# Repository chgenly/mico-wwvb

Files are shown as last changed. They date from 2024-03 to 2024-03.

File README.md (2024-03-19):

# &mu;WWVB: a tiny wwvb station

&mu;WWVB is a low power 60 khz [WWVB] transmitter used
to automatically set the time on radio synchronized clocks and wristwatches where the regular [WWVB] signal isn’t available. The system acquires
the correct time via GPS.

If you are interested in building a WWVB transmitter, I recommend you look at [pico wwvb](https://github.com/chgenly/pico-wwwvb).  It's much cheaper to build, and a lot less work.

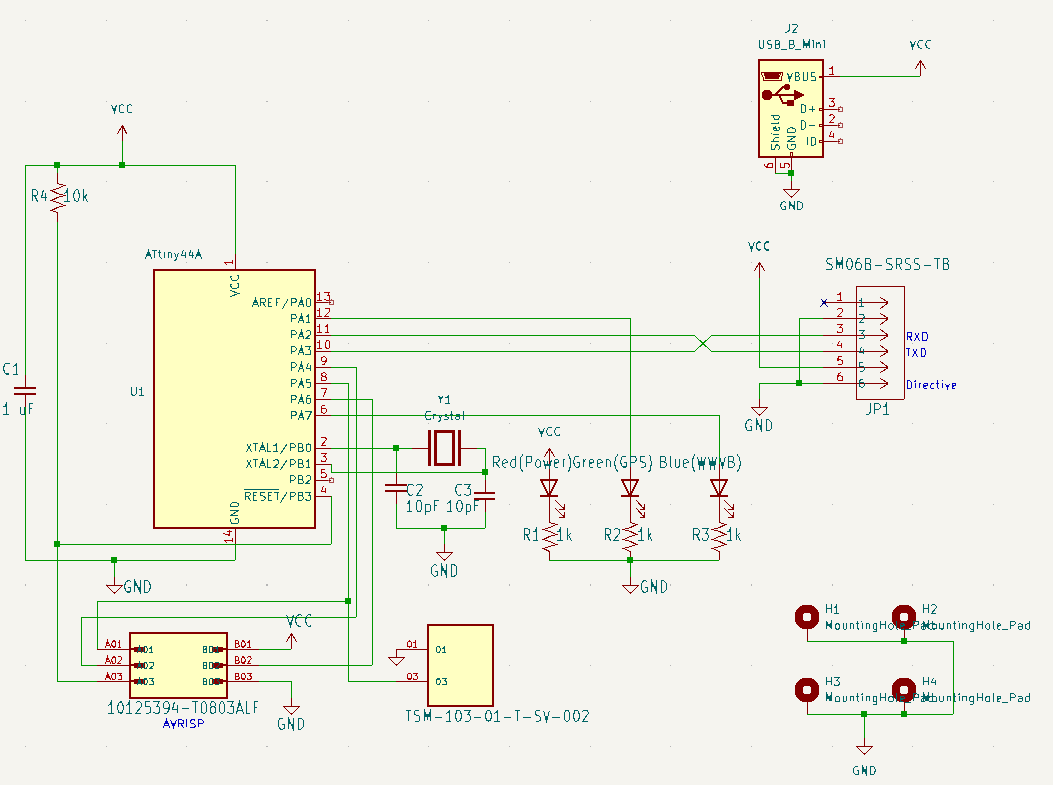
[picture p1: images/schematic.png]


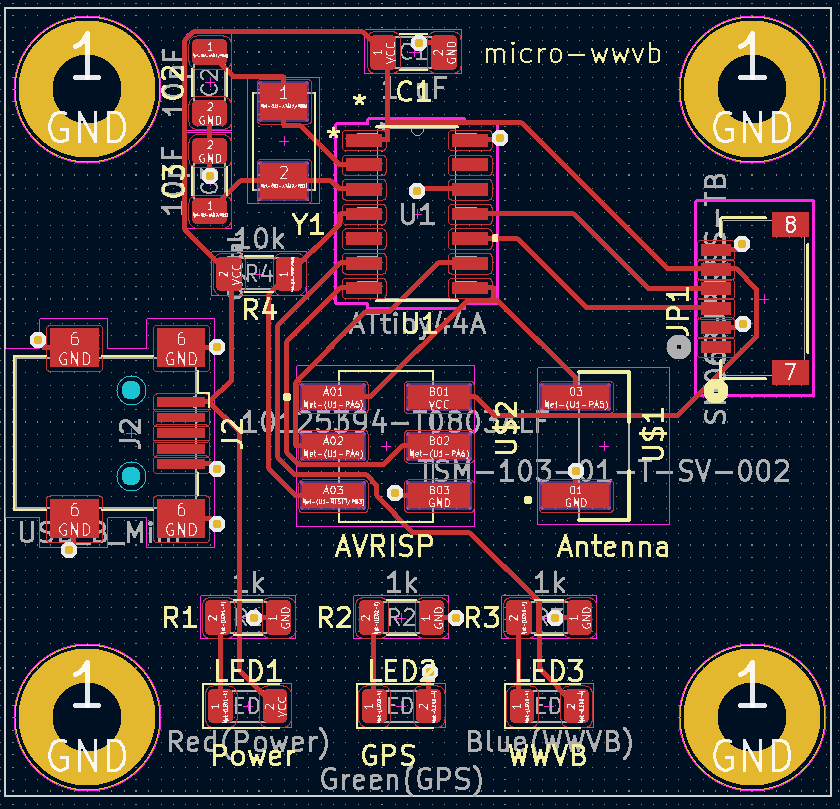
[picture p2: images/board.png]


## Anish Athalye's project

I started with this 2016 github project.

-  His github project https://github.com/anishathalye/micro-wwvb.git 
-  His [blog post][micro-wwvb-post].

Thanks to Anish for making it available. 

## My situation

I live in Forest Grove, Oregon.  The opposite coast where Anish had his problem. I'm not able to reliably receive [WWVB], and especially not inside my house.  

I started searching for information on WWVB signals and ran 
across Anish's project.  It was perfect for what I wanted to do.

Anish seemed to have access to a lot of equipment for building the physical part of the stand.    I don't have access so I'm just going to be using a simple plastic box as a case.

I haven't made my own PC board since 1974.  A lot of taping was involved and then an etching bath.  I was pleased to discover open source schematic and printed circuit board editors.  I was
also pleased to discover online services which would accept design files, either as [gerber files](https://en.wikipedia.org/wiki/Gerber_format) or kicad pcb files, and mail you a finished PCB.

## KiCad

For my open source schematic/PCB editor I chose [KiCad].  I had never used it before.  So there was a bit of a learning curve.

### autorouting
Install the Freerouting plugin.
1. Open KiCad Project Manager
1. Click on Plugin and Content Manager
1. Find Freerouting
1. Click on install
1. Click on Apply Pending Changes.
1. You will have to have Java installed for it to work.

## PCB fabrication service

I used [Osh Park](https://oshpark.com) as my fabrication service.  They accept KiCad pcb files directly.  No need to export to gerber files.  The are the cheapest service I could fine.  Interestingly, they just happen to be local to me.

[WWVB]: https://www.nist.gov/pml/time-and-frequency-division/radio-stations/wwvb
[micro-wwvb-post]: https://www.anishathalye.com/2016/12/26/micro-wwvb/

[KiCad]: https://www.kicad.org/

## ATTiny44a-SSUR

AVR family of processors.  8 bit risc architecture.

14 pin Dual inline package
Surfuce mount device

Just notes an decoding the suffix.

- 4KiB flash
- SS - 14S1 package
- U - Matte tin
- R - Tape and real
- 14S1 - 14-lead, 3.90 mm Narrow Body, Plastic Small Outline Package (SOIC)

## WWVB signal

WWVB transmit on 60 khz for atomic watches and clocks. One bit of data is sent once every second.
60 seconds are required to send all the bits for the time.
- 0: Power reduced for .2 seconds.
- 1: Power reduced for .5 seconds.
- mark: Power reduced for .8 seconds.

## Software

The top level software

1. Initialize pins for LEDs,  GPS serial communication and for the antenna. 
1. Loop
   1. Acquire time from GPS module
   1. Send the 1 minute WWVB signal ten times.

The 60 khz signal is generated using the ATTiny's 16 bit counter, and associated wave form generator.
The pulse width modulation output, PA5 (pin 8), is used to generate the 60khz signal.
The software divides a second into two parts.  The first part is the reduced power signal.  Reduced power in our case means no signal is sent.  The second part is full power signal.  Here pulse width modulation is set to 50% duty cycle.

Actually, a 20 khz signal is generated.  We depend on the third harmonic.  Apparently Anish found this more effective.

Timing for the signal is accomplished using a library routine to delay a certain number of milliseconds. I believe the millisecond
delay is trasformed to a cycle count delay.

During the full power signal, the blue led is turned on. The led is connected to PA7 (pin 6).

| Source file | Description |
|---|---|
| microwwvb.c | Top level.  init, get time, transmit time.|
| gps.c | Send and receive GPS module commands. |
| hardware.h  | Constants for LEDs, serial port |
| serial.c | Send and receive ascii data. |
| led.c | Show status on LEDs |

## Programming

For a description of using an arduino to program the micro-wwvb board see:

https://docs.arduino.cc/built-in-examples/arduino-isp/ArduinoISP

Here are the steps to use the arduino to program the micro-wwvb board.

1. Wire the Arduino to the micro-wwvb.
1. Program the Arduino as ISP.
1. Test program to make blue and green leds flash.
1. Update src/makefile
1. Program micro-wwvb

### Wire Arduino to the micro-wwvb

micro-wwwvb pin header, as seen when the usb connector is on the left.
<pre>
| miso  | vcc  |
| sck   | mosi |
| reset | gnd  |
</pre>

You'll need six male to female cables.

- miso - arduino 12
- sck - adruino 13
- reset - arduino 10
- vcc - arduino 5v
- mosi - arduino 11
- gnd - arduino gnd

Make sure to disconnnect the ferrite loop antenna during programming.

### Program the Arduino as ISP

- Connect Arduino uno to your laptop
- Start adrduino ide
- Select board: arduino uno
- Select comm: comm3 (for me)
- File / Examples/ Arduino ISP /ArduinoISP
- Sketch / Upload

## Test program to make blue and green leds flash

- File / Preferences
  - Select Show verbose output during compile and upload.
- Use the following sketch
- Select board: attiny44
- Select comm: com3 (for me)
  - You can use the windows device manager to help you find
    the com.  Look under Ports.
- Tools / Programmer / arduino as ISP
- Sketch / Upload using programmer

```c
// Flash blue and green LEDS.  Blue is on when green is off.
void setup() {
  pinMode(PA1, OUTPUT);
  pinMode(PA7, OUTPUT);
}

void loop() {
  digitalWrite(PA1, HIGH); 
  digitalWrite(PA7, LOW); 
  delay(100);
  digitalWrite(PA1, LOW);
  digitalWrite(PA7, HIGH);
  delay(100);
```

### Update src/makefile

The reason you turned on verbose mode in the previous step
was so you could see paths to various tools.  Look in the output window and look for the path to avr-gcc, avrdude, and avrdude-conf.
Then set the variables at the top of src/Makefile.

| Variable | Comment|
|---|---|
| GBIN | Should point to the directory containing avr-gcc.exe |
| DCONF | Should point to avrdude.conf |
| DBIN | Should be the directory containing avrdude.exe 

### Program micro-wwvb

Goto the src directory and run make.  I used cygwin make.

- make program-fuses
- make program

## LEDs

The LEDS will indicated status

| Time | LED states |
|---|-----|
| Program startup / top of loop | Green and blue flash three times |
| Waiting for start bit from GPS modules | Green  |
| Searching for the '$' at the start of the response from the GPS module | Blue |
| Complete time response received from GPS module | Green on |
| Failure to receive expected response from GPS module | Green blinks twice, then blue blinks twice. |
| While transmitting WWVB signal | Blue on for powered portion of the signal |

After startup, if the green and blue lights are stuck on,
you are not receiving anything from the GPS module.

After startup, if only the blue light is stuck on, 
you are receiving something from the GPS module, but the Initial '$' isn't being received.

If everything is working, you should see the Green light go solid, and the blue light flash
slowly with wwvb time data.

## Mechanical

To mount the gps module, which has no screw holes, I used a strap cut from a Fiji water bottle.  The Fiji bottle was rectangular, so I could cut out 
a relatively flat piece of plastic.  I created a template
in Gimp (image editor) and used a sharp craft knife to cut the plastic.

Here's the strap:
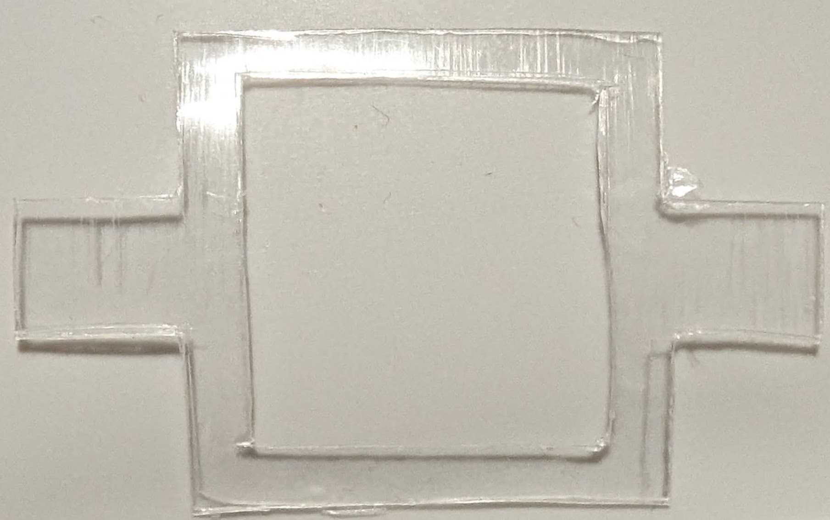
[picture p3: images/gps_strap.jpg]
GPS strap


You can see how the central hole is sized for the GPS module.
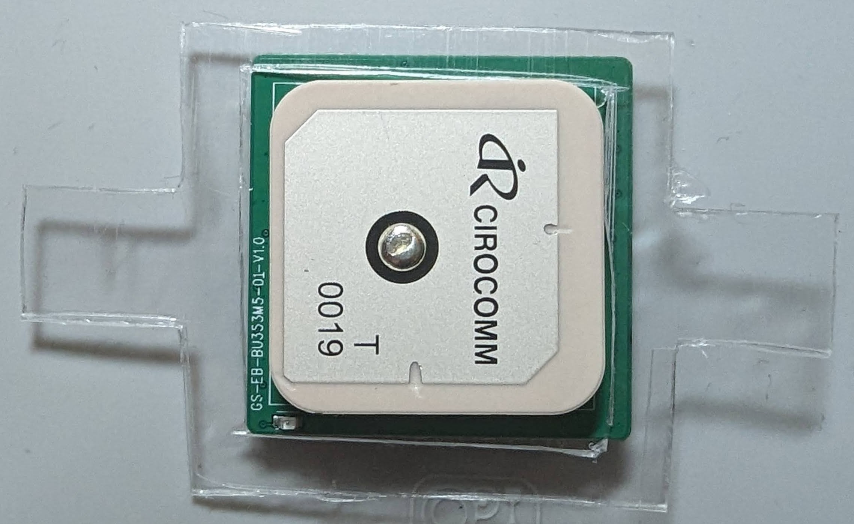
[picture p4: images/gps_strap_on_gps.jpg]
GPS strap on GPS module


I'll drill small holes in the tabs for screws.

I used a plastic food container as the case for the project.
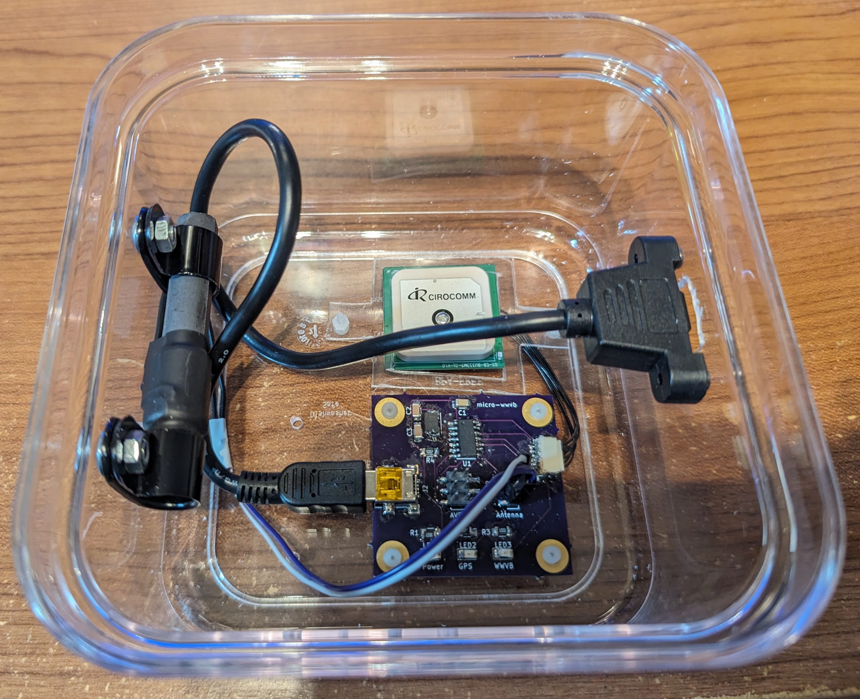
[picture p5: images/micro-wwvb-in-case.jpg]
micro-wwvb in a case

## Changes

### Board
My first attempt at the board was incorrect.  I got the order of the pins on the GPS connector backwards.  I didn't
realize the cable that came with the GPS module was a reversing cable.  I fixed this for my
purposes by using a non-reversing cable.  

I have updated the KiCAD files to fix the pin ordering problem.   The images of the schematic and
the board have been updated too.  However, I'v never had these boards manufactured, and so never 
tested the latest board design.  I don't expect you will have problems, but if you do, you can start looking there.

### GPS module

The original GPS modules was the EM-506.  Due to the pin ordering problem, I
burned out the GPS module.  When I went to reorder it, it wasn't available.
It had been changed to the EM-506N5.  They are largely compatible.  However
the module is no longer initialized using $PSRF commands, instead a
proprietary command, $PAIR, is used.  The software and the bill of materials
has been updated to reflect the new module.

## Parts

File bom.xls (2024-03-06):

Description | Quantity | Price | Total | Part Number | Url
Resistor 1K .5W 1206 | 3 | $0.40 | $1.20 | RNCP1206FTD1K00 | https://www.digikey.com/en/products/detail/stackpole-electronics-inc/RNCP1206FTD1K00/2240337
Resistor 10K .5W 1206 | 1 | $0.14 | $0.14 | RMEF1206FT10K0 | https://www.digikey.com/en/products/detail/stackpole-electronics-inc/RMEF1206FT10K0/16839774
Capacitor 30pf cer 1206 | 2 | $0.30 | $0.60 | VJ1206A300JXAAT | https://www.digikey.com/en/products/detail/vishay-vitramon/VJ1206A300JXAAT/8316072
Capacitor 1uf cer 1206 | 1 | $0.15 | $0.15 | CL31B105KBHNNNE | https://www.digikey.com/en/products/detail/samsung-electro-mechanics/CL31B105KBHNNNE/3886726
Capacitor 10uf cer (for arduino as ISP) | 1 | $0.49 | $0.49 | FG18X5R1E106MRT06 | https://www.digikey.com/en/products/detail/samsung-electro-mechanics/CL31A106KOHNNNE/3886795https://www.digikey.com/en/products/detail/tdk-corporation/FG18X5R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
20MHZ crystal | 1 | $0.55 | $0.55 | ABM3-20.000MHZ-B2-T | https://www.digikey.com/en/products/detail/abracon-llc/ABM3-20-000MHZ-B2-T/675300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
LED Red | 1 | $0.39 | $0.39 | SML-LX1206SRC-TR | https://www.digikey.com/en/products/detail/lumex-opto-components-inc/SML-LX1206SRC-TR/229141
LED Green | 1 | $0.41 | $0.41 | SML-LX1206SUGC-TR | https://www.digikey.com/en/products/detail/lumex-opto-components-inc/SML-LX1206SUGC-TR/467545
LED Blue | 1 | $1.81 | $1.81 | SML-LX1206USBC-TR | https://www.digikey.com/en/products/detail/lumex-opto-components-inc/SML-LX1206USBC-TR/467547
Attiny44a-SSUR | 1 | $1.03 | $1.03 | ATtiny44a-ssur | https://www.digikey.com/en/products/detail/microchip-technology/ATTINY44A-SSUR/2357401
usb-b mini | 1 | $1.51 | $1.51 | A-USB B-M5-SMD-C | https://www.digikey.com/en/products/detail/assmann-wsw-components/A-USB-B-M5-SMD-C/7917263
6 Pin 1mm R/A connector for GPS | 1 | $0.78 | $0.78 | SM06B-SRSS-TB | https://www.digikey.com/en/products/detail/jst-sales-america-inc./SM06B-SRSS-TB/926877
6 pin header smd for ISP | 1 | $0.55 | $0.55 | 10125394-T0803ALF | https://www.digikey.com/en/products/detail/amphenol-cs-fci/10125394-T0803ALF/7589635
3 pin header smd for antenna | 1 | $0.82 | $0.82 | TSM-103-01-L-SV-TR | https://www.digikey.com/en/products/detail/samtec-inc/TSM-103-01-L-SV-TR/6691760
3 pin connector for antenna | 1 | $0.37 | $0.37 | PPPC031LFBN-RC | https://www.digikey.com/en/products/detail/sullins-connector-solutions/PPPC031LFBN-RC/810175
male to female pin cables (20) | 1 | $2.10 | $2.10 |  | https://www.digikey.com/en/products/detail/sparkfun-electronics/PRT-12794/5993859
Case | 1 | $16.40 | $16.40 |  | https://www.digikey.com/en/products/detail/micro-connectors-inc/RAS-PCS06/12698330
USB to TTL serial | 1 | $9.95 | $9.95 |  | https://www.digikey.com/en/products/detail/adafruit-industries-llc/954/7064488
Loop stick antenna | 1 | $4.99 | $4.99 |  | https://www.amazon.com/CANADUINO-60kHz-Antenna-Atomic-Receiver/dp/B07PK7WJYR?s=electronics
GPS Module | 1 | $44.95 | $44.95 | EM-506N5 | https://www.sparkfun.com/products/19629
Elegoo UNO R3 | 1 | $16.99 | $16.99 |  | https://www.amazon.com/ELEGOO-Board-ATmega328P-ATMEGA16U2-Compliant/dp/B01EWOE0UU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
Osh Fabrication (3 boards) | 1 | $13.40 | $13.40 |  | https://oshpark.com
 |  | Total | $119.58

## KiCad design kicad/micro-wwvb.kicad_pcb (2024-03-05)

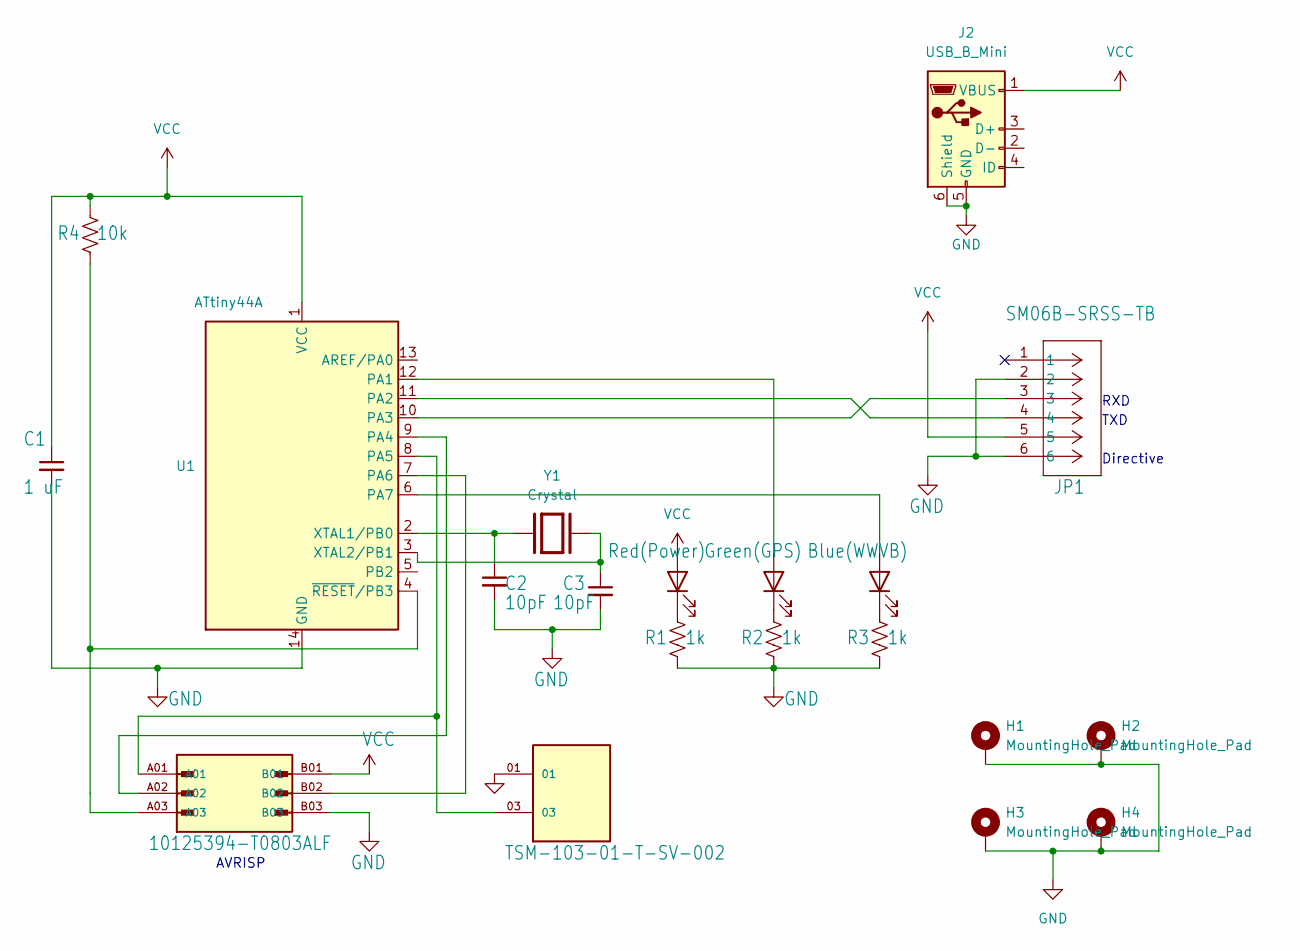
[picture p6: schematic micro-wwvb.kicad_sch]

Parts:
C1: 1 uF; C_1206_3216Metric_Pad1.33x1.80mm_HandSolder
C2, C3: 10pF; C_1206_3216Metric_Pad1.33x1.80mm_HandSolder
H1, H2, H3, H4: MountingHole_Pad; MountingHole_3.5mm_Pad
J2: USB_B_Mini; USB_Mini-B_Wuerth_65100516121_Horizontal
JP1: SM06B-SRSS-TB; CONN_SM06B-SRSS-TB_JST
LED1: Red(Power); LED_1206_3216Metric
LED2: Green(GPS); LED_1206_3216Metric
LED3: Blue(WWVB); LED_1206_3216Metric
R1, R2, R3: 1k; R_1206_3216Metric_Pad1.30x1.75mm_HandSolder
R4: 10k; R_1206_3216Metric_Pad1.30x1.75mm_HandSolder
U1: ATtiny44A; 14S1_ATM-M
U$1: TSM-103-01-T-SV-002; SAMTEC_TSM-103-01-T-SV-002
U$2: 10125394-T0803ALF; AMPHENOL_10125394-T0803ALF; PARTREV B
Y1: Crystal; XTAL_ABM3-20.000MHZ-B2-T; part number ABM3-20.000MHZ-B2-T

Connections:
GND: C1.2, C2.2, C3.2, H1.1, H2.1, H3.1, H4.1, J2.5 (GND), J2.6 (Shield), JP1.2, JP1.6, R1.1, R2.1, R3.1, U1.14 (GND), U$1.01, U$2.B03
unnamed: LED1.1 (K), R1.2
unnamed: LED2.2 (A), U1.12 (PA1)
unnamed: LED2.1 (K), R2.2
unnamed: LED3.2 (A), U1.6 (PA7)
unnamed: LED3.1 (K), R3.2
unnamed: JP1.4, U1.11 (PA2)
unnamed: JP1.3, U1.10 (PA3)
unnamed: U1.9 (PA4), U$2.A02
unnamed: U1.8 (PA5), U$1.03, U$2.A01
unnamed: U1.7 (PA6), U$2.B02
unnamed: C2.1, U1.2 (XTAL1/PB0), Y1.1
unnamed: C3.1, U1.3 (XTAL2/PB1), Y1.2
unnamed: R4.1, U1.4 (~RESET/PB3), U$2.A03
VCC: C1.1, J2.1 (VBUS), JP1.5, LED1.2 (A), R4.2, U1.1 (VCC), U$2.B01

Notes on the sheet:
TXD
RXD
AVRISP
Directive

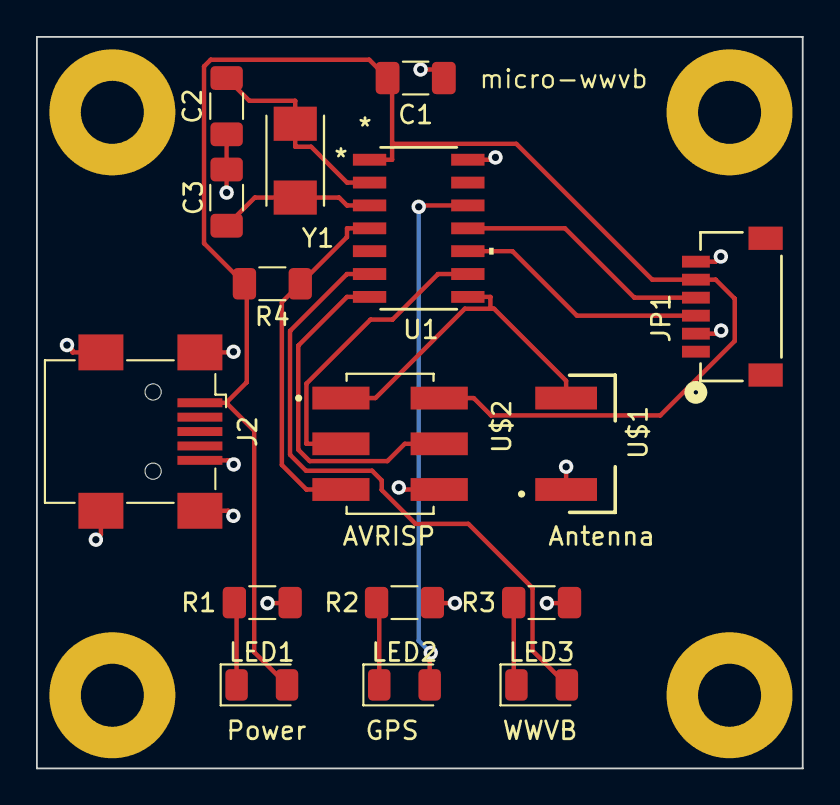
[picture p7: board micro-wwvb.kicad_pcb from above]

Board: 2 copper layers, 42.5 x 40.6 mm, 20 parts (0 on the bottom side), 15 nets.

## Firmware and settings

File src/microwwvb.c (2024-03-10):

// micro-wwvb: a tiny wwvb station
//
// set lfuse to 0x5E for 20 MHz xtal
// note that this code depends on the processor running at 20 MHz
//
// Copyright (c) Anish Athalye

// Define this if the gps module should
// be ignored, and we just send a fixed time.
//define SEND_TEST

#if (F_CPU != 20000000)
#error "Only 20 MHz CPU supported"
#endif

#include "serial.h"
#include "gps.h"
#include "hardware.h"
#include "led.h"
#include <avr/io.h>
#include <util/delay.h>

#define GPS_UPDATE_FREQ (10) // once every GPS_UPDATE_FREQ minutes

//For 20 khz
// #define ICR1_SETPOINT (999)
// For 60 khz
#define ICR1_SETPOINT (332)
#define HIGH (ICR1_SETPOINT/2) // 50% duty cycle
#define LOW (0) // 0% duty cycle

static inline void init();
static inline void gen_mark();
static inline void gen_zero();
static inline void gen_one();
static inline void broadcast_time(
    int hour,
    int minute,
    int second,
    int day,
    int month,
    int year,
    int max_transmissions
);
static inline int is_leap_year(int year);
static inline int day_of_year(int day, int month, int year);
static inline int day_of_week(long day, long month, long year); // 0 => sunday
static inline int is_daylight_savings_time(int day, int month, int year);

int main() {
    init();

    // Give the GPS module a chance to start, then initialize it.
    _delay_ms(1000);
    gps_init(&GPS_PORT, GPS_PORT_NUM, GPS_BAUD_RATE);

    int hour, minute, second, day, month, year;

    while (1) {
        led_loop_top();
#ifndef SEND_TEST
        int ret = gps_get_time(
            &GPS_PIN,
            GPS_PIN_NUM,
            GPS_BAUD_RATE,
            &year,
            &month,
            &day,
            &hour,
            &minute,
            &second
        );
        if (ret < 0) {
            led_error();
            continue; // failed, try again
        }
#else
        // hour = 10;
        // minute = 7;
        // second = 58;
        // day = 24;
        // month = 11;
        // year = 2023;

        hour = 0;
        minute = 15;
        second = 58;
        day = 1;
        month = 12;
        year = 2023;
#endif
        LED_G_PORT |= (1 << LED_G_PORT_NUM); // got lock
        broadcast_time(hour, minute, second, day, month, year, GPS_UPDATE_FREQ);
    }
}

static inline void broadcast_time(
    int hour,
    int minute,
    int second,
    int day,
    int month,
    int year,
    int max_transmissions
) {
    int broadcasts = 0;
    int doy = day_of_year(day, month, year);
    int leap = is_leap_year(year);
    int dst = is_daylight_savings_time(day, month, year);
    while (1) {
        // compute bit
        unsigned char bit=0; // 2 = mark, 1 = "1", 0 = "0"
        switch (second) {
            case 0: // mark
                bit = 2;
                break;
            case 1: // minute 40
                bit = ((minute / 10) >> 2) & 1;
                break;
            case 2: // minute 20
                bit = ((minute / 10) >> 1) & 1;
                break;
            case 3: // minute 10
                bit = ((minute / 10) >> 0) & 1;
                break;
            case 4: // blank
                bit = 0;
                break;
            case 5: // minute 8
                bit = ((minute % 10) >> 3) & 1;
                break;
            case 6: // minute 4
                bit = ((minute % 10) >> 2) & 1;
                break;
            case 7: // minute 2
                bit = ((minute % 10) >> 1) & 1;
                break;
            case 8: // minute 1
                bit = ((minute % 10) >> 0) & 1;
                break;
            case 9: // mark
                bit = 2;
                break;
            case 10: // blank
                bit = 0;
                break;
            case 11: // blank
                bit = 0;
                break;
            case 12: // hour 20
                bit = ((hour / 10) >> 1) & 1;
                break;
            case 13: // hour 10
                bit = ((hour / 10) >> 0) & 1;
                break;
            case 14: // blank
                bit = 0;
                break;
            case 15: // hour 8
                bit = ((hour % 10) >> 3) & 1;
                break;
            case 16: // hour 4
                bit = ((hour % 10) >> 2) & 1;
                break;
            case 17: // hour 2
                bit = ((hour % 10) >> 1) & 1;
                break;
            case 18: // hour 1
                bit = ((hour % 10) >> 0) & 1;
                break;
            case 19: // mark
                bit = 2;
                break;
            case 20: // blank
                bit = 0;
                break;
            case 21: // blank
                bit = 0;
                break;
            case 22: // doy of year 200
                bit = ((doy / 100) >> 1) & 1;
                break;
            case 23: // doy of year 100
                bit = ((doy / 100) >> 0) & 1;
                break;
            case 24: // blank
                bit = 0;
                break;
            case 25: // doy of year 80
                bit = (((doy / 10) % 10) >> 3) & 1;
                break;
            case 26: // doy of year 40
                bit = (((doy / 10) % 10) >> 2) & 1;
                break;
            case 27: // doy of year 20
                bit = (((doy / 10) % 10) >> 1) & 1;
                break;
            case 28: // doy of year 10
                bit = (((doy / 10) % 10) >> 0) & 1;
                break;
            case 29: // mark
                bit = 2;
                break;
            case 30: // doy of year 8
                bit = ((doy % 10) >> 3) & 1;
                break;
            case 31: // doy of year 4
                bit = ((doy % 10) >> 2) & 1;
                break;
            case 32: // doy of year 2
                bit = ((doy % 10) >> 1) & 1;
                break;
            case 33: // doy of year 1
                bit = ((doy % 10) >> 0) & 1;
                break;
            case 34: // blank
                bit = 0;
                break;
            case 35: // blank
                bit = 0;
                break;
            case 36: // UTI sign +
                bit = 1;
                break;
            case 37: // UTI sign -
                bit = 0;
                break;
            case 38: // UTI sign +
                bit = 1;
                break;
            case 39: // mark
                bit = 2;
                break;
            case 40: // UTI correction 0.8
                bit = 0;
                break;
            case 41: // UTI correction 0.4
                bit = 0;
                break;
            case 42: // UTI correction 0.2
                bit = 0;
                break;
            case 43: // UTI correction 0.1
                bit = 0;
                break;
            case 44: // blank
                bit = 0;
                break;
            case 45: // year 80
                bit = (((year / 10) % 10) >> 3) & 1;
                break;
            case 46: // year 40
                bit = (((year / 10) % 10) >> 2) & 1;
                break;
            case 47: // year 20
                bit = (((year / 10) % 10) >> 1) & 1;
                break;
            case 48: // year 10
                bit = (((year / 10) % 10) >> 0) & 1;
                break;
            case 49: // mark
                bit = 2;
                break;
            case 50: // year 8
                bit = ((year % 10) >> 3) & 1;
                break;
            case 51: // year 4
                bit = ((year % 10) >> 2) & 1;
                break;
            case 52: // year 2
                bit = ((year % 10) >> 1) & 1;
                break;
            case 53: // year 1
                bit = ((year % 10) >> 0) & 1;
                break;
            case 54: // blank
                bit = 0;
                break;
            case 55: // leap year
                bit = leap ? 1 : 0;
                break;
            case 56: // leap second
                bit = 0;
                break;
            case 57: // dst bit 1
                bit = dst ? 1 : 0; // XXX this isn't exactly correct
                break;
            case 58: // dst bit 2
                bit = dst ? 1 : 0;
                break;
            case 59: // mark
                bit = 2;
                break;
        }

        if (second == 0)
            G_OFF;

        // transmit bit
        if (bit == 0) {
            gen_zero();
        } else if (bit == 1) {
            gen_one();
        } else {
            gen_mark();
        }

        if (second == 0)
            G_ON;

        // increment time (or give up and ask GPS for a new time)
        if (++second >= 60) {
            second = 0;
            // quit after max_transmissions
            if (++broadcasts >= max_transmissions) {
                return;
            }
            if (++minute >= 60) {
                minute = 0;
                if (++hour >= 24) {
                    // be lazy, just ask the GPS for a new time
                    return;
                }
            }
        }
    }
}

static inline int is_leap_year(int year) {
    return (year % 4 == 0) && (year % 100 != 0 || year % 400 == 0);
}

static inline int day_of_week(long day, long month, long year) {
    // via https://en.wikipedia.org/wiki/Julian_day
    long a = (14 - month) / 12;
    long y = year + 4800 - a;
    long m = month + 12 * a - 3;
    long jdn = day + (153 * m + 2) / 5 + 365 * y +
        (y / 4) - (y / 100) + (y / 400) - 32045;

    return (jdn + 1) % 7;
}

static inline int day_of_year(int day, int month, int year) {
    static const short cum_days_in_month[] = {
        0,
        31,
        59,
        90,
        120,
        151,
        181,
        212,
        243,
        273,
        304,
        334
    }; // cumulative
    return cum_days_in_month[month - 1] + day + (is_leap_year(year) & (month > 2));
}

static inline int is_daylight_savings_time(int day, int month, int year) {
    // according to NIST
    // begins at 2:00 a.m. on the second Sunday of March
    // ends at 2:00 a.m. on the first Sunday of November

    if (month <= 2 || 12 <= month) return 0;
    if (4 <= month && month <= 10) return 1;

    // only march and november left
    int dow = day_of_week(day, month, year);
    if (month == 3) {
        return (day - dow > 7);
    } else {
        // month == 11
        return (day - dow <= 0);
    }
}

static inline void init() {
    // set clock divider to /1
    CLKPR = (1 << CLKPCE);
    CLKPR = (0 << CLKPS3) | (0 << CLKPS2) | (0 << CLKPS1) | (0 << CLKPS0);

    // for GPS
    GPS_PORT_DDR |= (1 << GPS_PORT_NUM); // set to an output port
    GPS_PORT |= (1 << GPS_PORT_NUM); // initialize
    GPS_PIN_DDR &= ~ (1 << GPS_PIN_NUM); // set to an input pin

    // for LEDs
    LED_G_PORT_DDR |= (1 << LED_G_PORT_NUM); // set to an output port
    G_OFF; // turn off
    LED_B_PORT_DDR |= (1 << LED_B_PORT_NUM); // set to an output port
    B_OFF; // turn off

    // for antenna
    // initialize non-inverting fast PWM on OC1B (PA5)
    TCCR1A = (1 << COM1B1) | (0 << COM1B0) | (1 << WGM11) | (0 << WGM10);
    // count from BOTTOM to ICR1 (mode 14), using /1 prescaler
    TCCR1B = (1 << WGM13) | (1 << WGM12) | (0 << CS12) | (0 << CS11) | (1 << CS10);
    // fast PWM:
    // f = f_clk / (N * (1 + TOP)), where N is the prescaler divider
    // for f = 60 kHz, we want N * (1 + TOP) = 333.3
    // we're using a prescaler of 1, so we want ICR1 = TOP = 332
    // this gives an f = 60.06 kHz
    // we can use OCR1B to set duty cycle (a fraction of ICR1)
    //
    // actually, f = 20 kHz seems to work a lot better and then 60 kHz is the
    // third harmonic - in this case, we get ICR1 = 999
    ICR1 = ICR1_SETPOINT;
    OCR1B = LOW; // by default, have a low output
    DDRA |= (1 << PA5); // set PA5 to an output port
}

static inline void gen_mark() {
    OCR1B = LOW;
    B_OFF;
    _delay_ms(800);
    OCR1B = HIGH;
    B_ON;
    _delay_ms(200);
    OCR1B = LOW;
    B_OFF;
}

static inline void gen_zero() {
    OCR1B = LOW;
    B_OFF;
    _delay_ms(200);
    OCR1B = HIGH;
    B_ON;
    _delay_ms(800);
    OCR1B = LOW;
    B_OFF;
}

static inline void gen_one() {
    OCR1B = LOW;
    B_OFF;
    _delay_ms(500);
    OCR1B = HIGH;
    B_ON;
    _delay_ms(500);
    OCR1B = LOW;
    B_OFF;
}

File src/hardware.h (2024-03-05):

#ifndef HARDWARE_H
#define HARDWARE_H

#include "serial.h"
#include <avr/io.h>

#define GPS_BAUD_RATE BAUD_RATE_4800
#define GPS_PORT PORTA
#define GPS_PORT_DDR DDRA
#define GPS_PORT_NUM PA3
#define GPS_PIN PINA
#define GPS_PIN_DDR DDRA
#define GPS_PIN_NUM PA2

#define LED_G_PORT PORTA
#define LED_G_PORT_DDR DDRA
#define LED_G_PORT_NUM PA1
#define LED_B_PORT PORTA
#define LED_B_PORT_DDR DDRA
#define LED_B_PORT_NUM PA7

#endif // HARDWARE_H

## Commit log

2023-10-27 Initial checkin
    [bom.xls, micro-wwvb.kicad_pcb, micro-wwvb.kicad_sch]
2023-10-27 Added silkscreen text to the back. Updated README.md with ATTiny info.
    [micro-wwvb.kicad_pcb]
2023-10-28 Working on the bom
    [bom.xls]
2023-10-28 More bom changes. Sparkfun want to charge $30 for shipping. So i moved away from them.
    [bom.xls]
2023-10-28 Updated BOM to what was actually ordered. Add 3 pin hdr library for antenna. Although I'm not using this on the board I ordered. If I spin it again, I'll use this.
    [bom.xls]
2023-11-14 LEDs show more status. Updated README.md.
2024-02-28 SEND_TEST: If defined in microwwvb.c the GPS module will be ignored and a fixed time will be sent.
    [micro-wwvb.kicad_pcb]
2024-03-05 Yikes! I reversed all the pins on the gps connector.
    I didn't realize the plug had to be turned
    upside down to fit it into the connector.
    The kicad files have been updated. It also seems
    I've swapped the transmit and receive on the gps
    connector. I've updated the code to compensate.
    Found compatibility problems when using a windows
    version of make. Updated the makefile.
    [micro-wwvb.kicad_pcb, micro-wwvb.kicad_sch]
2024-03-05 Clarified LED states.
2024-03-05 Updated the images for the schematic and board with gps pin order corrected.
2024-03-05 Added led_debug() to help debugging. Calls are dropped into the code at various points to see if they are reached. Production code should not call this.
2024-03-06 The new GPS module does not support $PSRF commands.
    The EM506 supports $PSRF for initialization. The EM506N5 uses the $PAIR command for initialization.
    [bom.xls]
2024-03-08 Updated REAME.md with pointer to pico-wwvb, changed how leds indicate an error.
    [led.h, microwwvb.c]
2024-03-10 Sometimes the GPS module doesn't respond to initialization commands. I added a one second delay before initializing the module.
    [microwwvb.c]
2024-03-15 Added pictures and a description for the GPS strap.
2024-03-19 Add picture of micro wwvb in a case.
